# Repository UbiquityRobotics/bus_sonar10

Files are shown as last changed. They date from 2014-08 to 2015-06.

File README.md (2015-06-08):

# bus_sonar10

The Sonar10 board is used to drive up to 10 HC-SR04
sonar modules.

Currently, everything is located in the `rev_a` directory.

## Revision A

The revision A schematic is available as either
`bus_sonar10.pdf` or as `bus_sonar10.svg`.

Logic ground comes in on N1 (pins 3 and 4).  Logic
power comes in on N1 (pins 1 and 2.)  The logic power
is routed to C1, U2 (a LM2940-5.0), C4, C5, and R1.
The C4/R1 series combination is used to bring the
ESR of C5 to less than 1 ohm as required by the
LM2940 spec. sheet.  Capacitors C6, C7, C8, C9, and
C11 provide filter capacitors for the various IC's.

The MCP2562 CAN bus transceiver (U3) is connected to
CANH (N1 pin 5) and CANL (N1 pin 6).  In addition,
R6 and J1 can be used to enable a 120 ohm CAN bus
termination resistor.  VIO (U3 pin 5) is connected
to 5V since all digital signals on this board are
running at 5V.

The AND gate at U1A is used to or the signals from
the MCP2562 TXD (U3 pin 1) with the TXD signal on
the 3.3V FTDI USB serial cable (N2 pin 4).  R4 is
a 100K ohm pull resistor that pulls serial cable
high if no serial cable is plugged in.  (There should
be a similar 100K pull-up resistor on the MCP2662
to pull it high if the MCP2562 CAN bus transceiver
is not plugged in.  It was accidently left out.)
The output of the 74HCT08 and gate is directed to
RXD (U4 pin 2) of the ATmega328P.  The 74HCT08 is
used to level shift from 3.3V on the serial cable
up to 5V output on U1A.  (Note: in Rev. A the TXD
and RXD pins on U3 are accidentally swapped.)  Lastly,
the TXD output from the processor is sent to the R2/R3
voltage divider that takes the 0-5V signal down to 0-3V.

One other comment about the serial cable.  If a 5V FTDI
serial cable gets plugged into N2, nothing bad happens
because U1 has 5V tolerant inputs.

The reset signal is derived from RTS on the serial cable
(N2 pin 6.)  Normally, RTS on the serial cable idles
at 3.3V high, which is buffered through AND gate U1B
to 5V.  The othe end of C10 is pulled up to 5V through
10K resistor (R7).  Since both ends of C10 are at 5V,
C10 is discharged and has 0V across it.  When RTS goes
low, the output of U1B goes low.  This immediately pulls
the #RESET line low and that resets the processor on
its #RESET line (U4 pin 1).  Now R7 has 5V across it
and it starts to charge C10 up to 5V.  When downloading
is done, The serial cable signal RTS goes back high again.
This the causes the U1B AND output to go high (5V).
This causes the other end of C10 to attempt to pull
the #RESET line up to 10V (since C10 has 5V across it.)
Luckily the Schottky diode D1 to clamp the voltage
on the #RESET line to 5.2V and rapidly discharge C10
again.  Lastly, the button SW1 can be used to trigger
a reset as well.

(There was a theory that the AVR counter/timers could
be used to time the width of a pulse.  For this reason,
all sonar echos were run into the input pins of
5 (OC2B), 11 (OC0B), 12 (OC0A), 15 (OC1A), 16 (OC1B),
and 17 (OC2A).  Alas, this theory turned out to be
false.)

Order to support 10 sonars, pairs of echo return signals
from the HC-SR04 modules are combined using the 74HCT32
quad OR gate U5.  By using these 4 OR gates, the 10
sonar echos are directed to 6 input pins.  This is good
because 6 input pins are all that is available.

All the connections are summerized in the table below:
<BlockQuote>
  <Table Border="1">
    <TR>
      <TH RowSpan="2">Sonar</TH>
      <TH ColSpan="4">Trigger</TH>
      <TH ColSpan="7">Echo</TH>
    </TR><TR>
      <TH>Pin</TH>
      <TH>Arduino</TH>
      <TH>Port-Bit </TH>
      <TH>Conn-Pin</TH>
      <TH>Pin</TH>
      <TH>Arduino</TH>
      <TH>Counter</TH>
      <TH>Port-Bit</TH>
      <TH>PCINT</TH>
      <TH>Conn-Pin</TH>
    </TR><TR>
      <TD>0</TD>
      <TD>24</TD>
      <TD>A1</TD>
      <TD>PC1</TD>
      <TD>N3-5</TD>
      <TD RowSpan="2">15</TD>
      <TD RowSpan="2">D9</TD>
      <TD RowSpan="2">OC1A</TD>
      <TD RowSpan="2">PB1</TD>
      <TD RowSpan="2">PCINT1</TD>
      <TD>N3-3</TD>
    </TR><TR>
      <TD>1</TD>
      <TD>19</TD>
      <TD>D13</TD>
      <TD>PB5</TD>
      <TD>N3-13</TD>
      <TD>N3-11</TD>
    </TR><TR>
      <TD>2</TD>
      <TD>23</TD>
      <TD>A0</TD>
      <TD>PC0</TD>
      <TD>N3-21</TD>
      <TD>12</TD>
      <TD>D6</TD>
      <TD>OC0A</TD>
      <TD>PD6</TD>
      <TD>PCINT22</TD>
      <TD>N3-19</TD>
    </TR><TR>
      <TD>3</TD>
      <TD>18</TD>
      <TD>D12</TD>
      <TD>PB4</TD>
      <TD>N3-29</TD>
      <TD RowSpan="2">11</TD>
      <TD RowSpan="2">D5</TD>
      <TD RowSpan="2">OC0B</TD>
      <TD RowSpan="2">PD5</TD>
      <TD RowSpan="2">PCINT21</TD>
      <TD>N3-27</TD>
    </TR><TR>
      <TD>4</TD>
      <TD>14</TD>
      <TD>D8</TD>
      <TD>PB0</TD>
      <TD>N3-37</TD>
      <TD>N3-35</TD>
    </TR><TR>
      <TD>5</TD>
      <TD>26</TD>
      <TD>A3</TD>
      <TD>PC3</TD>
      <TD>N4-5</TD>
      <TD RowSpan="2">17</TD>
      <TD RowSpan="2">D11</TD>
      <TD RowSpan="2">OC2A</TD>
      <TD RowSpan="2">PB3</TD>
      <TD RowSpan="2">PCINT3</TD>
      <TD>N4-3</TD>
    </TR><TR>
      <TD>6</TD>
      <TD>25</TD>
      <TD>A2</TD>
      <TD>PC2</TD>
      <TD>N4-13</TD>
      <TD>N4-11</TD>
    </TR><TR>
      <TD>7</TD>
      <TD>13</TD>
      <TD>D7</TD>
      <TD>PD7</TD>
      <TD>N4-21</TD>
      <TD>16</TD>
      <TD>D10</TD>
      <TD>OC1B</TD>
      <TD>PB2</TD>
      <TD>PCINT2</TD>
      <TD>N4-19</TD>
    </TR><TR>
      <TD>8</TD>
      <TD>6</TD>
      <TD>D4</TD>
      <TD>PD4</TD>
      <TD>N4-29</TD>
      <TD RowSpan="2">5</TD>
      <TD RowSpan="2">D3</TD>
      <TD RowSpan="2">OC2B</TD>
      <TD RowSpan="2">PD3</TD>
      <TD RowSpan="2">PCINT19</TD>
      <TD>N4-27</TD>
    </TR><TR>
      <TD>9</TD>
      <TD>4</TD>
      <TD>D2</TD>
      <TD>PD2</TD>
      <TD>N4-37</TD>
      <TD>N4-35</TD>
    </TR>
  </Table>
</BlockQuote>

### Issues

* The TXD and RXD pins on the MCP2562 (U3 pins 1 and 4) are
  swapped. [x]

* It would be nice to have an LED that can be blinked. [x]

* Tie unused inputs of U1 to one rail or the other. [x]

* Put a 100K pull up on U1A (pin 1) to deal with MCP2652 not
  being plugged in.. [x]

* Think about finding an extra pin for STBY on the MCP2652
  rather than just grounding it. [x]

* References for D1 and R7 are transposed. [x]

### Rev. C

- No ISP connector.

## Software

The software is developed using the arduino-mk package.
You may have to edit the Makefile if you are not using
a standard Ubuntu configuration and/or an 3.3V FTDI USB
to serial cable.

The software is in `bus_sonar10.ino`.

To build the code:

        make

To upload the code to bus_sonar10 over the FTDI serial cable:

        make upload

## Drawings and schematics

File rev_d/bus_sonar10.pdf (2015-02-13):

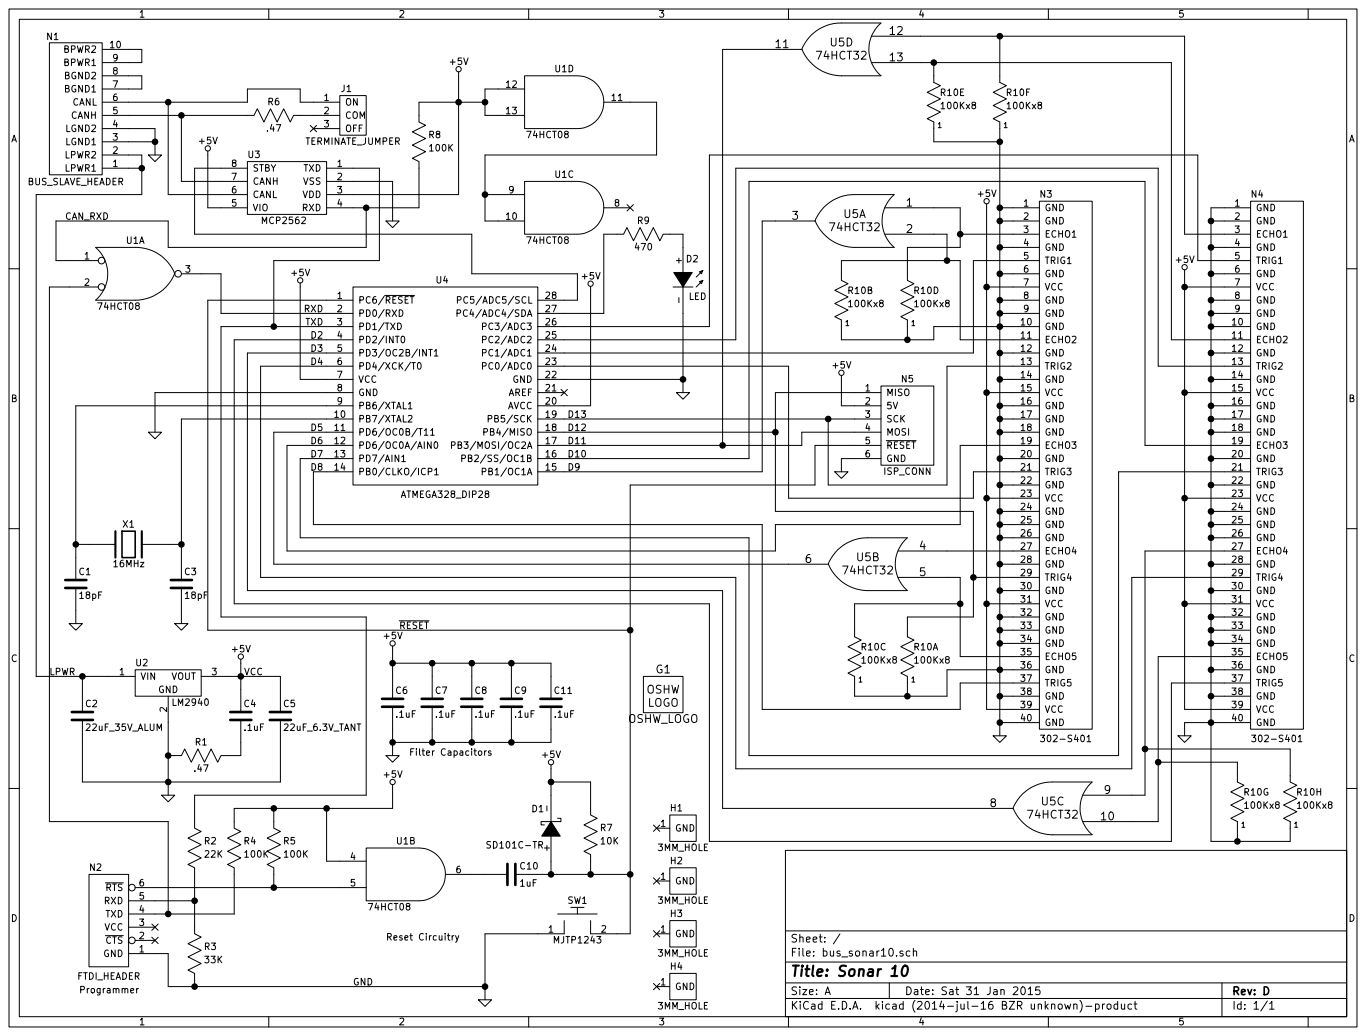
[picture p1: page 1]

RXD
TXD

File: bus_sonar10.sch Sheet: / GND 1 H1

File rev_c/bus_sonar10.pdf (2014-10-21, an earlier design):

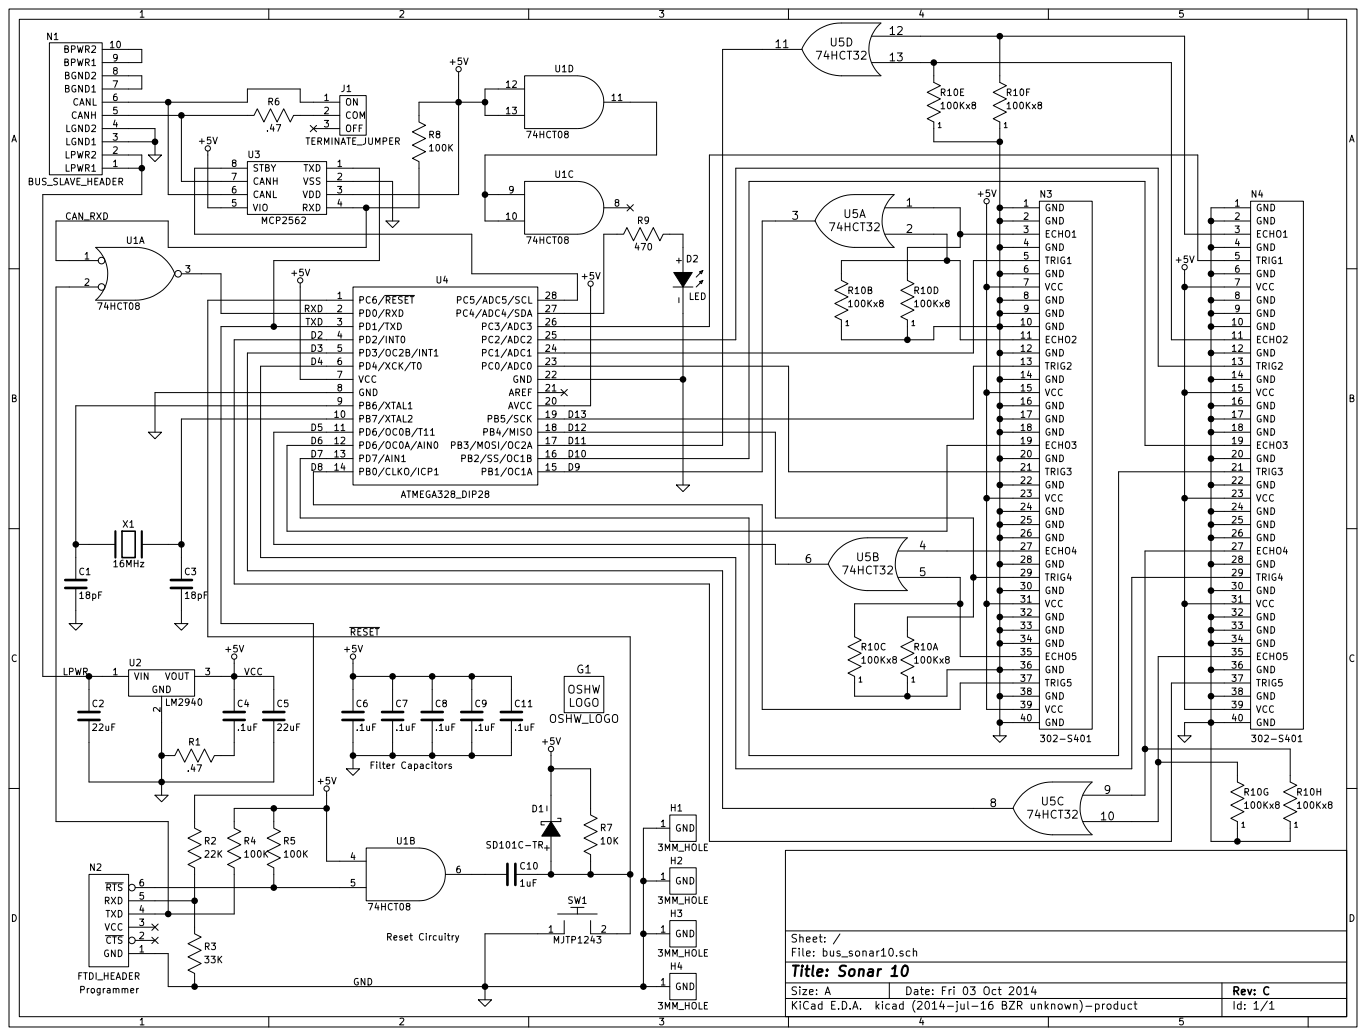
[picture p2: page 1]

RXD
TXD

File: bus_sonar10.sch Sheet: / GND 1 H1

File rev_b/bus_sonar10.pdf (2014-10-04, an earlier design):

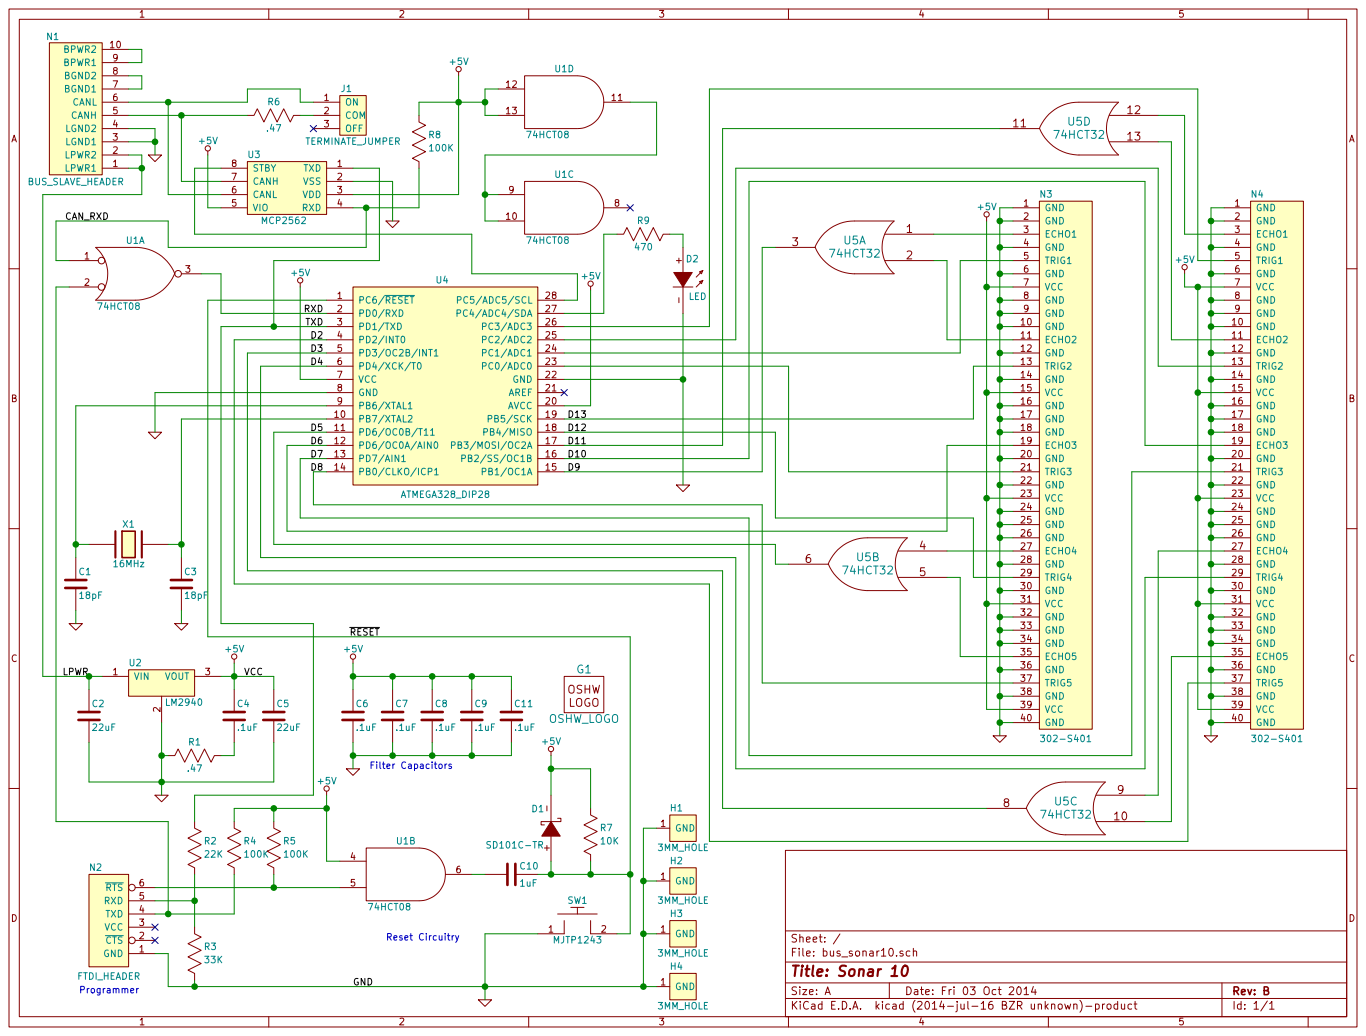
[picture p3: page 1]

RXD
TXD

File: bus_sonar10.sch Sheet: / GND 1 H1

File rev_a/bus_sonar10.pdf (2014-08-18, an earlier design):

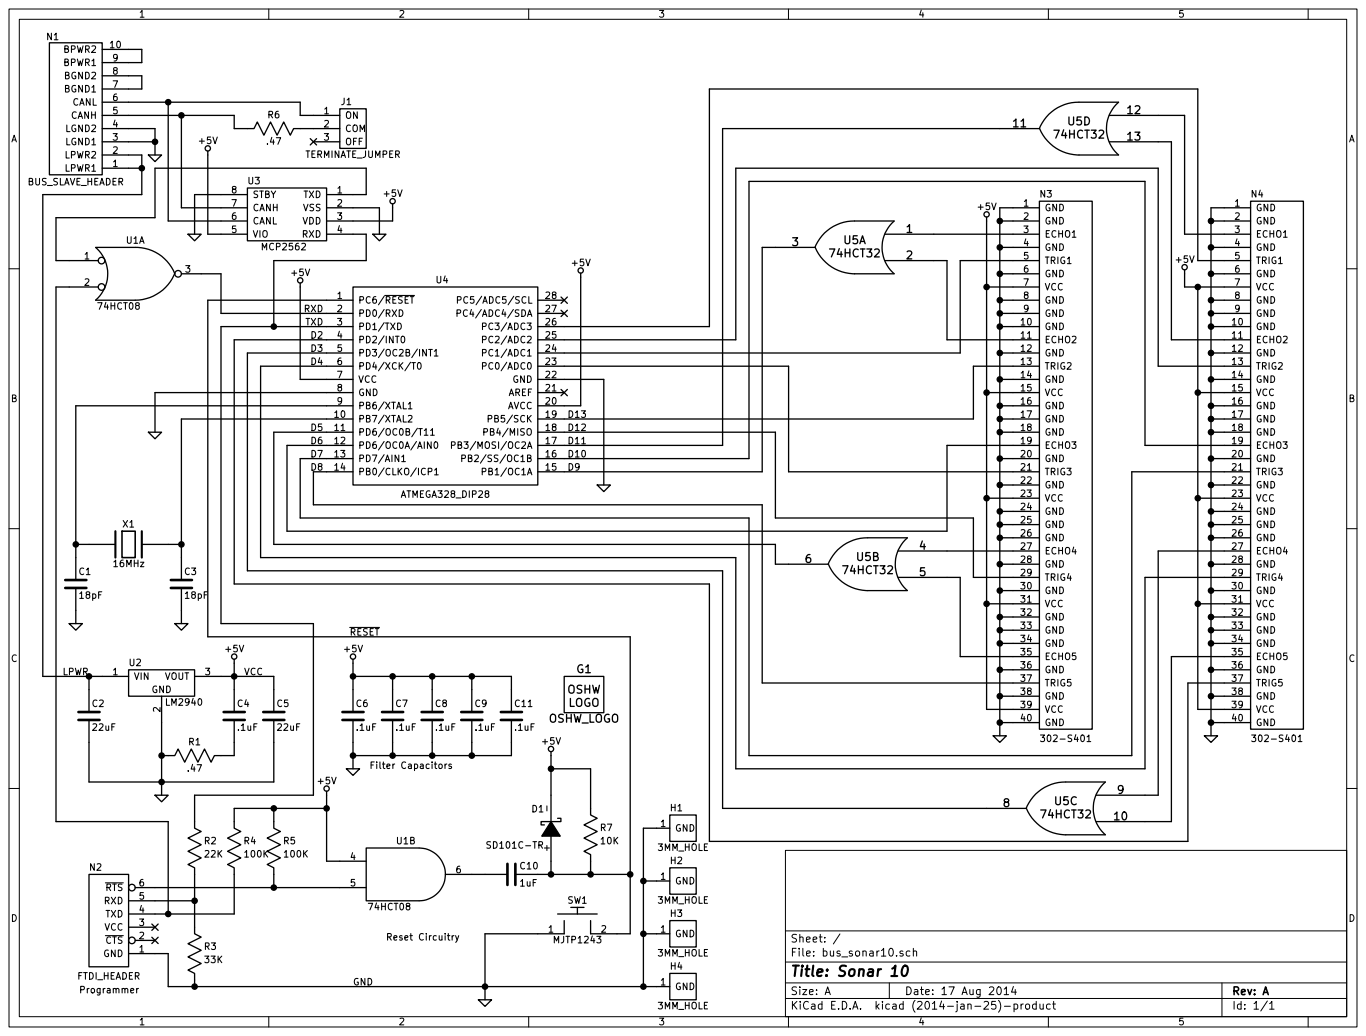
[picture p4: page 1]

RXD
TXD

File: bus_sonar10.sch Sheet: / GND 1 H1

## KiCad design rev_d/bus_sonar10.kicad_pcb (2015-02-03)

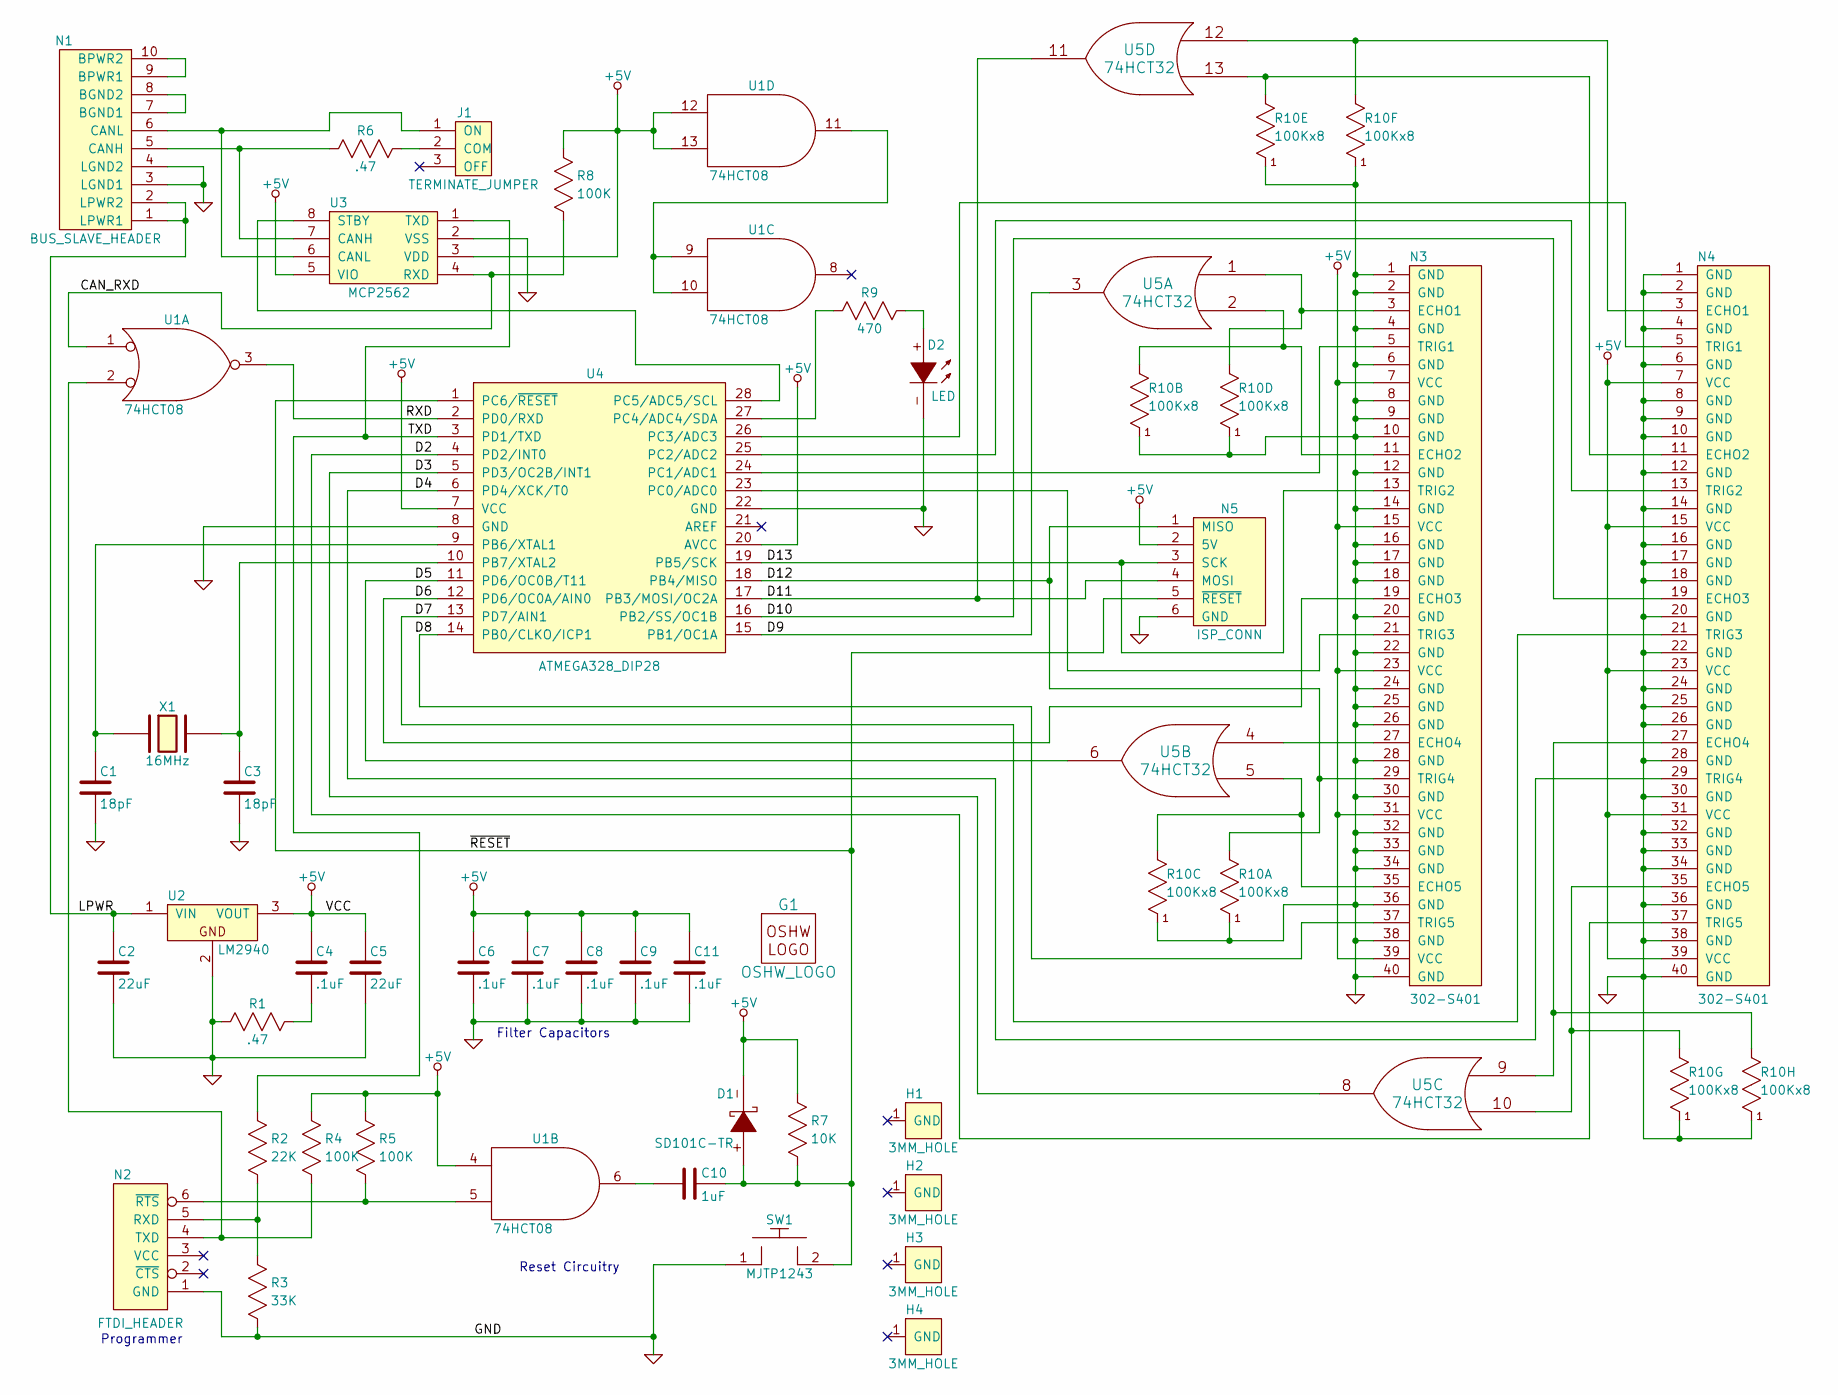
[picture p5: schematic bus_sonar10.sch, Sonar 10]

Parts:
C1, C3: 18pF; Capacitor3MMDiscRM2.5
C2, C5: 22uF; Capacitor4x3RM2-5_RevB
C4, C6, C7, C8, C9, C11: .1uF; Capacitor3MMDiscRM2.5
C10: 1uF; Capacitor3MMDiscRM2.5
D1: SD101C-TR; Diode_DO-41_SOD81_Horizontal_RM10
D2: LED; T1_LED
G1: OSHW_LOGO; OSHW_LOGO_400mil
H1, H2, H3, H4: 3MM_HOLE; MountingHole_3mm
J1: TERMINATE_JUMPER; Pin_Header_Straight_1x03
N1: BUS_SLAVE_HEADER; Pin_Header_Straight_2x05_Shrouded
N2: FTDI_HEADER; Pin_Header_Straight_1x06
N3, N4: 302-S401; Pin_Header_Straight_2x20_Shrouded
N5: ISP_CONN; Pin_Header_Straight_2x03
R1, R6: .47; Resistor_Horizontal_400
R2: 22K; Resistor_Horizontal_400
R3: 33K; Resistor_Horizontal_400
R4, R5, R8: 100K; Resistor_Horizontal_400
R7: 10K; Resistor_Horizontal_400
R9: 470; Resistor_Horizontal_400
R10: 100Kx8; Pin_Header_Straight_1x09
SW1: MJTP1243; Button_6.5MM
U1: 74HCT08; DIP-14__300
U2: LM2940; TO-220_Neutral123_Horizontal_LargePads
U3: MCP2562; DIP-8__300
U4: ATMEGA328_DIP28; DIP-28__300
U5: 74HCT32; DIP-14__300
X1: 16MHz; Crystal_HC49-U_Vertical

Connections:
/CAN_RXD: R8.1, U1.1, U3.4 (RXD)
/D2: N4.37 (TRIG5), U4.4 (PD2/INT0)
/D3: U4.5 (PD3/OC2B/INT1), U5.8
/D4: N4.29 (TRIG4), U4.6 (PD4/XCK/T0)
/D5: U4.11 (PD6/OC0B/T11), U5.6
/D6: N3.19 (ECHO3), U4.12 (PD6/OC0A/AIN0)
/D7: N4.21 (TRIG3), U4.13 (PD7/AIN1)
/D8: N3.37 (TRIG5), U4.14 (PB0/CLKO/ICP1)
/D9: U4.15 (PB1/OC1A), U5.3
/D10: N4.19 (ECHO3), U4.16 (PB2/SS/OC1B)
/D11: N5.4 (MOSI), U4.17 (PB3/MOSI/OC2A), U5.11
/D12: N3.29 (TRIG4), N5.1 (MISO), R10.2, U4.18 (PB4/MISO)
/D13: N3.13 (TRIG2), N5.3 (SCK), U4.19 (PB5/SCK)
/LPWR: C2.1, N1.1 (LPWR1), N1.2 (LPWR2), U2.1 (VIN)
/RXD: U1.3, U4.2 (PD0/RXD)
/TXD: R2.2, U3.1 (TXD), U4.3 (PD1/TXD)
/~RESET: C10.2, D1.+, N5.5 (~RESET), R7.1, SW1.2, U4.1 (PC6/~RESET)
GND: C1.2, C2.2, C3.2, C5.2, C6.2, C7.2, C8.2, C9.2, C11.2, D2.-, N1.3 (LGND1), N1.4 (LGND2), N2.1 (GND), N3.1 (GND), N3.2 (GND), N3.4 (GND), N3.6 (GND), N3.8 (GND), N3.9 (GND), N3.10 (GND), N3.12 (GND), N3.14 (GND), N3.16 (GND), N3.17 (GND), N3.18 (GND), N3.20 (GND), N3.22 (GND), N3.24 (GND), N3.25 (GND), N3.26 (GND), N3.28 (GND), N3.30 (GND), N3.32 (GND), N3.33 (GND), N3.34 (GND), N3.36 (GND), N3.38 (GND), N3.40 (GND), N4.1 (GND), N4.2 (GND), N4.4 (GND), N4.6 (GND), N4.8 (GND), N4.9 (GND), N4.10 (GND), N4.12 (GND), N4.14 (GND), N4.16 (GND), N4.17 (GND), N4.18 (GND), N4.20 (GND), N4.22 (GND), N4.24 (GND), N4.25 (GND), N4.26 (GND), N4.28 (GND), N4.30 (GND), N4.32 (GND), N4.33 (GND), N4.34 (GND), N4.36 (GND), N4.38 (GND), N4.40 (GND), N5.6 (GND), R1.1, R3.1, R10.1, SW1.1, U1.7 (GND), U2.2, U3.2 (VSS), U4.8 (GND), U4.22 (GND), U5.7 (GND)
unnamed: C1.1, U4.9 (PB6/XTAL1), X1.1
unnamed: C3.1, U4.10 (PB7/XTAL2), X1.2
unnamed: C4.2, R1.2
unnamed: C10.1, U1.6
unnamed: D2.+, R9.2
unnamed: J1.1 (ON), N1.6 (CANL), U3.6 (CANL)
unnamed: J1.2 (COM), R6.2
unnamed: N1.5 (CANH), R6.1, U3.7 (CANH)
unnamed: N1.7 (BGND1), N1.8 (BGND2)
unnamed: N1.9 (BPWR1), N1.10 (BPWR2)
unnamed: N2.4 (TXD), R4.1, U1.2
unnamed: N2.5 (RXD), R2.1, R3.2
unnamed: N2.6 (~RTS), R5.1, U1.5
unnamed: N3.3 (ECHO1), R10.5, U5.1
unnamed: N3.5 (TRIG1), U4.24 (PC1/ADC1)
unnamed: N3.11 (ECHO2), R10.3, U5.2
unnamed: N3.21 (TRIG3), U4.23 (PC0/ADC0)
unnamed: N3.27 (ECHO4), U5.4
unnamed: N3.35 (ECHO5), R10.4, U5.5
unnamed: N4.3 (ECHO1), R10.7, U5.12
unnamed: N4.5 (TRIG1), U4.26 (PC3/ADC3)
unnamed: N4.11 (ECHO2), R10.6, U5.13
unnamed: N4.13 (TRIG2), U4.25 (PC2/ADC2)
unnamed: N4.27 (ECHO4), R10.9, U5.9
unnamed: N4.35 (ECHO5), R10.8, U5.10
unnamed: R9.1, U4.27 (PC4/ADC4/SDA)
unnamed: U1.9, U1.10, U1.11
unnamed: U3.8 (STBY), U4.28 (PC5/ADC5/SCL)
VCC: C4.1, C5.1, C6.1, C7.1, C8.1, C9.1, C11.1, D1.-, N3.7 (VCC), N3.15 (VCC), N3.23 (VCC), N3.31 (VCC), N3.39 (VCC), N4.7 (VCC), N4.15 (VCC), N4.23 (VCC), N4.31 (VCC), N4.39 (VCC), N5.2 (5V), R4.2, R5.2, R7.2, R8.2, U1.4, U1.12, U1.13, U1.14 (VCC), U2.3 (VOUT), U3.3 (VDD), U3.5 (VIO), U4.7 (VCC), U4.20 (AVCC), U5.14 (VCC)

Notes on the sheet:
Filter Capacitors
Reset Circuitry
Programmer

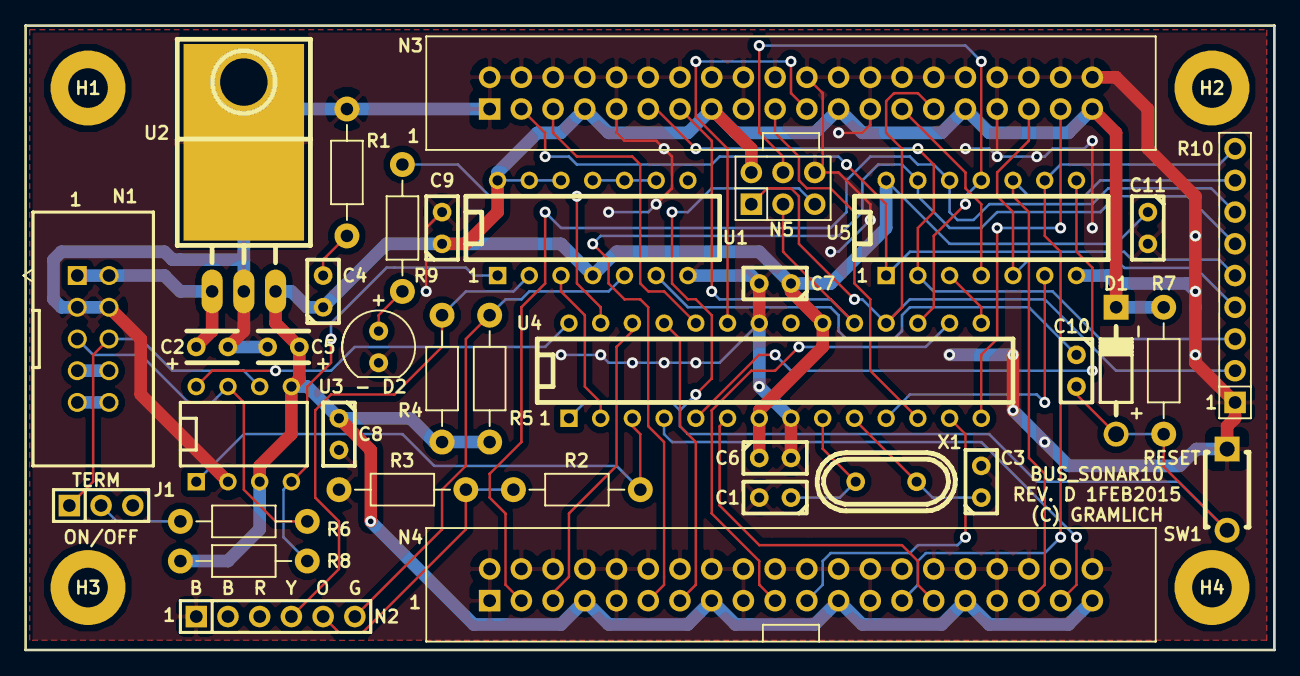
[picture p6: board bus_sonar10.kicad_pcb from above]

Board: 2 copper layers, 100.0 x 50.0 mm, 41 parts (1 on the bottom side), 47 nets.

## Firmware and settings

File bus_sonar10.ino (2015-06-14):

// Copyright (c) 2014-2015 by Wayne C. Gramlich.  All rights reserved.
// Some code came from the ros_arduino_bridge.

// The following tests are implemented by this code:
#define TEST_BUS_INPUT 1
#define TEST_BUS_OUTPUT 2
#define TEST_BUS_ECHO 3
#define TEST_BUS_COMMAND 4

// Set TEST to one of the possible tests:
#define TEST TEST_BUS_COMMAND

// Watch-out the code for SerialHardwared.cpp has been modified to
// notice this #define.  It causes the 8-ibt interrupt driver for
// UART1 to be disabled:
#define UART1_DISABLED

#include <Bus_Slave.h>
#include <Bus_Sonar10_Local.h>
#include <Sonar.h>

// This is the initial address of the module:
static UByte address = 41;

// The null object can be used for *debug_uart*:
NULL_UART null_uart;

// Debug *debug_uart* and *bus_uart* pointers:
#if defined(UDR1)
  UART *debug_uart = (UART *)&avr_uart0;
  UART *bus_uart = (UART *)&avr_uart1;
#else // defined(UDR1)
  UART *debug_uart = (UART *)&null_uart;
  UART *bus_uart = (UART *)&avr_uart0;
#endif // defined(UDR1)

Sonar_Queue b_sonar_queue(0, &PINB, debug_uart);
Sonar_Queue d_sonar_queue(2, &PIND, debug_uart);

// Create the sonar data structures:
Sonar sonar0(&PINC, 1, &b_sonar_queue, 1, 1);	// [0]: fails
Sonar sonar1(&PINB, 5, &b_sonar_queue, 1, 1);	// [1]: fails
Sonar sonar2(&PINC, 0, &d_sonar_queue, 22, 6);	// [2]: fails
Sonar sonar3(&PINB, 4, &d_sonar_queue, 21, 5);	// [3]: fails ?
Sonar sonar4(&PINB, 0, &d_sonar_queue, 21, 5);	// [4]:
Sonar sonar5(&PINC, 3, &b_sonar_queue, 3, 3);	// [5]: works
Sonar sonar6(&PINC, 2, &b_sonar_queue, 3, 3);	// [6]: works
Sonar sonar7(&PIND, 7, &b_sonar_queue, 2, 2);	// [7]: works
Sonar sonar8(&PIND, 4, &d_sonar_queue, 19, 3);	// [8]:
Sonar sonar9(&PIND, 2, &d_sonar_queue, 19, 3);	// [9]:

Sonar *sonars[] = {
  &sonar0,
  &sonar1,
  &sonar2,
  &sonar3,
  &sonar4,
  &sonar5,
  &sonar6,
  &sonar7,
  &sonar8,
  &sonar9,
  (Sonar *)0,
};

Sonar_Queue *sonar_queues[] = {
  &b_sonar_queue,
  &d_sonar_queue,
  (Sonar_Queue *)0,
};

UByte xsonars_schedule[] = {
  4, Sonars_Controller::GROUP_END,
  Sonars_Controller::SCHEDULE_END,
};

UByte sonars_schedule[] = {
  0, 5, Sonars_Controller::GROUP_END,
  1, 6, Sonars_Controller::GROUP_END,
  2, 7, Sonars_Controller::GROUP_END,
  3, 8, Sonars_Controller::GROUP_END,
  4, 9, Sonars_Controller::GROUP_END,
  Sonars_Controller::SCHEDULE_END,
};

Sonars_Controller sonars_controller((UART *)debug_uart,
 sonars, sonar_queues, sonars_schedule);

// Define the pin names alphabetically:
static const UByte bus_standby_pin = A5;
static const UByte led_pin = 13;

Bus_Slave bus_slave(bus_uart, debug_uart);
Bus_Sonar10 bus_sonar10(address);

// Do the two ISR's for the Sonar here:

ISR(PCINT0_vect) {
  b_sonar_queue.interrupt_service_routine();
}

ISR(PCINT2_vect) {
  d_sonar_queue.interrupt_service_routine();
}

UByte command_process(Bus_Slave *bus_slave, 
 UByte command, Logical execute_mode) {
  return bus_sonar10.command_process(bus_slave,
   command, execute_mode);
}

void loop() {
  switch (TEST) {
    case TEST_BUS_COMMAND: {
      // Encoder positions and state:

      // Deal with any *bus* related activities:
      bus_slave.slave_mode(address, command_process);
      sonars_controller.poll();

      //UShort changes_mask = sonars_controller.changes_mask_get();
      //if ((changes_mask & 0xc0) != 0) {
      //  for (UByte sonar_index = 0; sonar_index < 10; sonar_index++) {
      //    debug_uart->integer_print(sonar_index);
      //    debug_uart->string_print((Text)":");
      //    UShort mm_distance = sonars_controller.mm_distance_get(sonar_index);
      //    debug_uart->integer_print(mm_distance);
      //    debug_uart->string_print((Text)" ");
      //  }
      //  debug_uart->string_print((Text)"\r\n");
      //}

      break;
    }
    case TEST_BUS_ECHO: {
      // Wait for a *frame* to show up on *bus*:
      UShort frame = bus_slave.frame_get();

      // Set the *LED* to the least significant bit of *frame*:
      if ((frame & 1) == 0) {
        digitalWrite(led_pin, LOW);
      } else {
        digitalWrite(led_pin, HIGH);
      }

      // Print *frame* out to *debug_uart*:
      debug_uart->frame_put(frame & 0x7f);

      // Send out a CRLF when we get a '_':
      if (frame == (UShort)'_') {
        debug_uart->string_print((Character *)"\r\n");
      }

      // Now send *frame* back to the *bus*:
      bus_slave.frame_put(frame);

      // Get the *echo_frame* and check for a mismatch;
      UShort echo_frame = bus_slave.frame_get();
      if (frame != echo_frame) {
        debug_uart->string_print((Character *)"!");
      }

      break;
    }
    case TEST_BUS_OUTPUT: {
      // This test will just output characters to the debugging port
      // with no interraction with the bus:

      // Start with with *character* being static:
      static Character character = '@';

      // Just in case, make sure *character* is between '@' and '_':
      if (character < '@' || character > '_') {
	character = '@';
      }

      // Output *character* to the *debug_uart*:
      //debug_uart->frame_put((UShort)character);
      UDR0 = character;

      // Output any needed CRLF, and increment *character*:
      if (character == '_') {
	debug_uart->string_print((Character *)"\r\n");
	character = '@';
      } else {
	character += 1;
      }

      if ((character & 1) == 0) {
	digitalWrite(led_pin, LOW);
      } else {
	digitalWrite(led_pin, HIGH);
      }

      // Slow things down a little:
      delay(100);

      break;
    }
    case TEST_BUS_INPUT: {
      // This test will input *frame*'s from the *bus* and echo them
      // to *debug_uart*:

      // Get a *frame* from the bus:
      UShort frame = bus_slave.frame_get();

      // Print it out for debugging:
      debug_uart->frame_put(frame & 0x7f);

      // Tack on a CRLF when we get an '_':    
      if (frame == (UShort)'_') {
	debug_uart->string_print((Character *)"\r\n");
      }

      // Light the *LED* using the least significant bit of *frame*:
      if ((frame & 1) == 0) {
	digitalWrite(led_pin, LOW);
      } else {
	digitalWrite(led_pin, HIGH);
      }
      break;
    }
  }
}

void setup() {
  // The standard frequency for an AVR Arduino is 16MHz:
  static const UInteger frequency = (UInteger)16000000L;

  // Initalize the *debug_uart*:
  debug_uart->begin(frequency, 115200L, (Character *)"8N1");

  // Turn *LED* on:
  pinMode(led_pin, OUTPUT);
  digitalWrite(led_pin, HIGH);

  // Get *bus_uart* talking to the bus:
  bus_uart->begin(frequency, 500000L, (Character *)"9N1");

  // Force the standby pin on the CAN transeciever to low to force it
  // into active mode:
  pinMode(bus_standby_pin, OUTPUT);
  digitalWrite(bus_standby_pin, LOW);

  // Set up the sonar controller software module:
  sonars_controller.initialize();

  // Enable/disable interrupts based on *TEST*:
  switch (TEST) {
    case TEST_BUS_OUTPUT:
      debug_uart = &avr_uart0;
      debug_uart->begin(frequency, 115200L, (Text)"8N1");
      debug_uart->string_print((Character *)"\r\nbbes_output:\r\n");
      debug_uart->interrupt_set((Logical)0);
      bus_uart->interrupt_set((Logical)0);
      break;
    case TEST_BUS_INPUT:
      debug_uart->string_print((Character *)"\r\nbbes_input:\r\n");
      debug_uart->interrupt_set((Logical)1);
      bus_uart->interrupt_set((Logical)1);
      break;
    case TEST_BUS_ECHO:
      debug_uart->string_print((Character *)"\r\nbbes_echo:\r\n");
      debug_uart->interrupt_set((Logical)0);
      bus_uart->interrupt_set((Logical)0);
      break;
    case TEST_BUS_COMMAND:
      debug_uart->string_print((Character *)"\r\nbbes_command:\r\n");
      debug_uart->interrupt_set((Logical)1);
      bus_uart->interrupt_set((Logical)1);
      break;
  }
}

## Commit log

2014-08-17 Started from a clone of bus_bridge_encoders_sonar.
    [bus_sonar10.kicad_pcb, bus_sonar10.sch]
2014-08-18 Finnished laying out Rev. A
    [bus_sonar10-B_Cu.gbl, bus_sonar10-B_Mask.gbs, bus_sonar10-B_SilkS.gbo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]
2014-08-18 Added silkscreen outline.
    [bus_sonar10-B_Cu.gbl, bus_sonar10-B_Mask.gbs, bus_sonar10-B_SilkS.gbo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]
2014-10-04 Updated fp-lib-table for Rev. A, but did not load the new net into the PCB. This is in preparation for making a Rev. B clone of Rev. A.
2014-10-04 Cloned Rev. B from Rev. A.
    [bus_sonar10.kicad_pcb, bus_sonar10.sch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]
2014-10-04 Imported the new network into Rev. B.
    [bus_sonar10-B_Cu.gbl, bus_sonar10-B_Mask.gbs, bus_sonar10-B_SilkS.gbo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]
2014-10-04 Got Rev. B in pretty good shape.
    [bus_sonar10-B_Cu.gbl, bus_sonar10-B_Mask.gbs, bus_sonar10-B_SilkS.gbo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]
2014-10-17 Checked in gerbers for Rev. B. Cloned Rev. B for Rev. C
    [bus_sonar10-B_Cu.gbl, bus_sonar10-B_Mask.gbs, bus_sonar10-B_SilkS.gbo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]
2014-10-20 Wrapped up Rev. C
    [bus_sonar10-B_Cu.gbl, bus_sonar10-B_Mask.gbs, bus_sonar10-B_SilkS.gbo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]
2014-10-20 Made sure that Rev. C was up to date.
    [bus_sonar10-B_Cu.gbl, bus_sonar10-B_Mask.gbs, bus_sonar10-B_SilkS.gbo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]
2014-10-21 Changed 8 100K's to 8 100Kx8's.
    [bus_sonar10.sch]
2015-01-28 Missing IPS connector.
2015-02-01 Cloned Rev. C to Rev. D
    [bus_sonar10.kicad_pcb, bus_sonar10.sch]
2015-02-01 Added ISP connector.
    [bus_sonar10-B_Cu.gbl, bus_sonar10-B_Mask.gbs, bus_sonar10-B_SilkS.gbo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]
2015-02-03 Mounting holes are now electrically isolated.
    [bus_sonar10-B_Cu.gbl, bus_sonar10-B_Mask.gbs, bus_sonar10-B_SilkS.gbo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]
2015-02-13 Split 22uF capacitor into aluminum and tantalum.
    [bus_sonar10.sch]
2015-05-29 Configured a simple framework for the sonars. This code only compiles and has not been tested.
2015-06-03 Copied over code from bus_bridge_encoders_sonar and changed it to compile and 'work' for bus_sonar10. Most of the code is silly since it references stuff on the bus_bridge_encoders_sonar board.
2015-06-04 Got bus_sonar10 to return ficticious sonar data over the bus.
2015-06-04 Removed unused and unneed encoder registers from bus_sonar10.
2015-06-07 Refactored the code so that Sonar.{h,cpp} no longer needs RAB_Sonar{h,cpp}. This touched a bunch of files.
    [bus_sonar10.ino]
2015-06-08 Started adding Sonar_Queue objects.
2015-06-08 Removed concept of unit number for sonars.
2015-06-08 Added Sonar_Queue object to Sonar.
2015-06-08 Switch Sonar() constructor to use bit numbers rather than bit masks for argument values.
2015-06-09 More prep. work for Sonar_Queue's.
2015-06-09 Sonar_Controller=>Sonars_Controller. Add sonars_schedule argument to constructor.
2015-06-11 Started doxygen documentation for Sonar. Removed an argument from Sonar() constructor.
2015-06-12 Added sonar change mask to indicate whic sonar distances have changed.
2015-06-14 Fixed Sonar so that it does not screw up on sonars.
    [bus_sonar10.ino]
